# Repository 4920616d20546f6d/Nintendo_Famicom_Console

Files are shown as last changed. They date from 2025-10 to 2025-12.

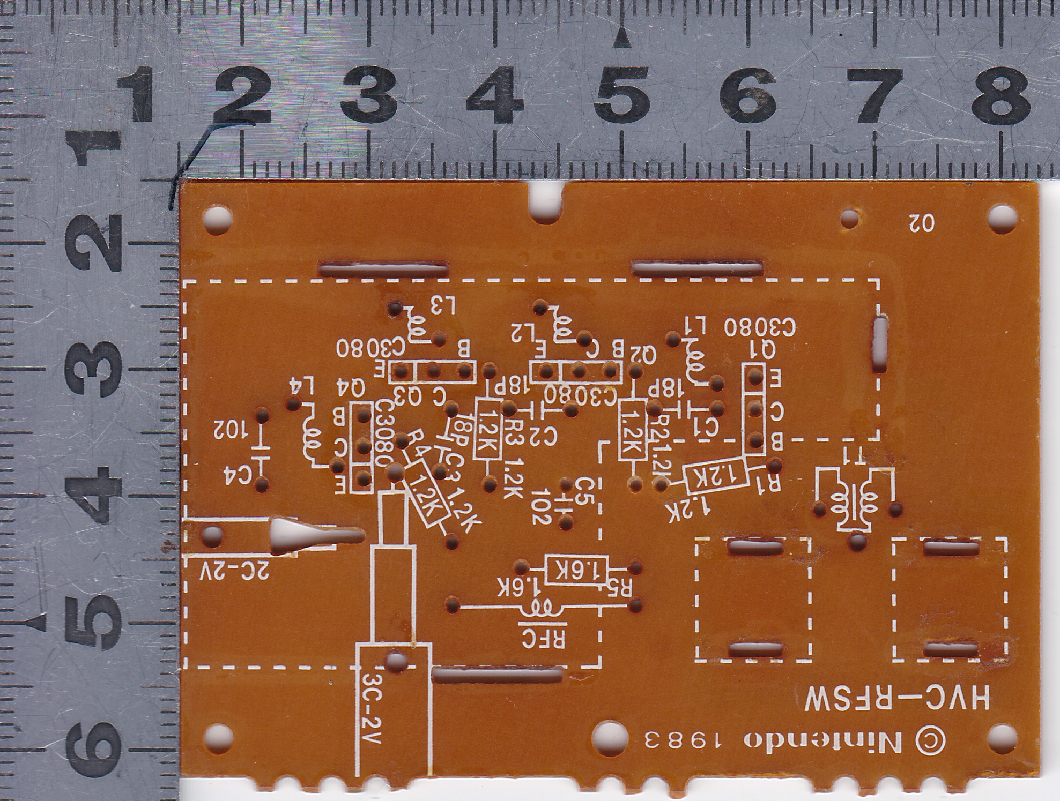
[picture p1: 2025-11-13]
RF_SWITCH/pcb_front_measure.jpg

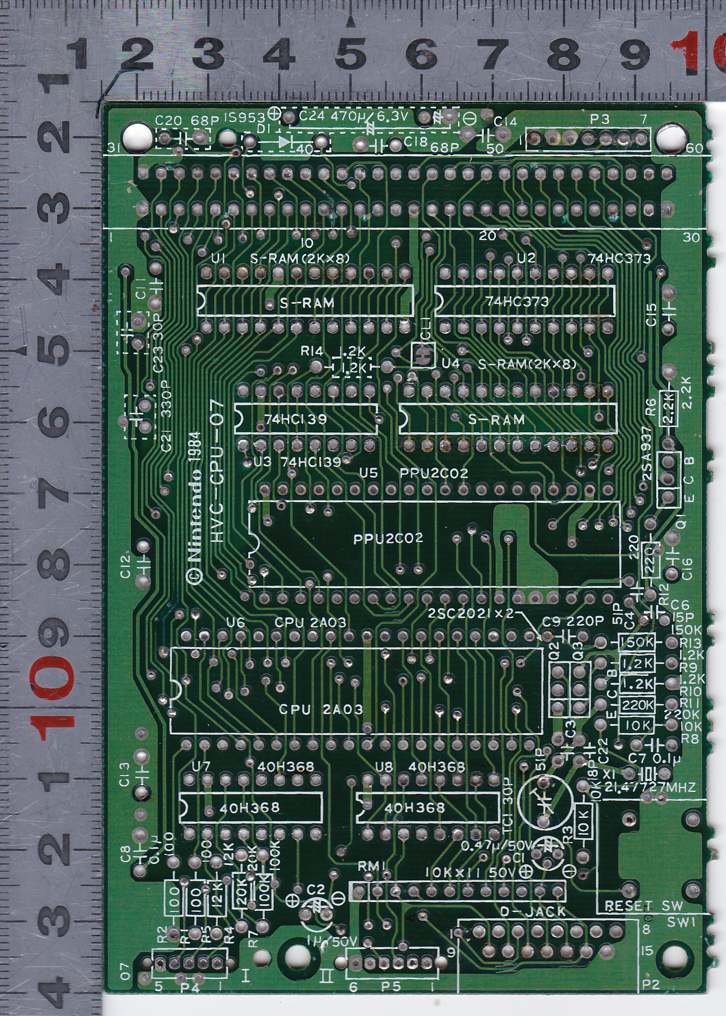
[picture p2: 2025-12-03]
HVC-CPU-07/pcb_front_measure.jpg

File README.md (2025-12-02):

# Goals
This project documents the Nintendo Family Computer from Japan. The goal is to provide complete, verified, schematics and PCB for every version of the console and essential accessories.

# Progress
- December 1, HVC-CPU-GPM-02 all footprints reviewed. Holes and pads corrected. Revision uploaded.
- November 30, HVC-CPU-GPM-02 verified to be electrically correct. There are 3 mechanical errors. The drill sizes for the 15 pin connector, TC1, and Reset switch are too small. Drills and annulus will be adjusted in next revision.
- November 27, HVC-CPU-07 acquired
- November 12, 2025 the HVC-CPU-GPM-02 mainboard was sent out for manufacturing.
- November 10, 2025 the first versions of all essential hardware and accessories have been complete and added to the repository.

# Project Status
## Console HVC-001
| Revision | Schematic | Symbols | Datasheets | Notes | PCB | Footprint | Pads | Masks | Text | Graphics | Models | Photos | Ready for Manufacturer | Manufactured |
|---|---|---|---|---|-----|---|---|---|---|---|---|---|---|---|
| HVC-CPU | ❌ | ❌ | ❌ | ❌ | ❌ | ❌ | ❌ | ❌ | ❌ | ❌ | ❌ | ❌ | ❌ | ❌ |
| HVC-CPU-02 | ❌ | ❌ | ❌ | ❌ | ❌ | ❌ | ❌ | ❌ | ❌ | ❌ | ❌ | ❌ | ❌ | ❌ |
| HVC-CPU-03 | ❌ | ❌ | ❌ | ❌ | ❌ | ❌ | ❌ | ❌ | ❌ | ❌ | ❌ | ❌ | ❌ | ❌ |
| HVC-CPU-04 | ❌ | ❌ | ❌ | ❌ | ❌ | ❌ | ❌ | ❌ | ❌ | ❌ | ❌ | ❌ | ❌ | ❌ |
| HVC-CPU-05 | ❌ | ❌ | ❌ | ❌ | ❌ | ❌ | ❌ | ❌ | ❌ | ❌ | ❌ | ❌ | ❌ | ❌ |
| HVC-CPU-06 | ❌ | ❌ | ❌ | ❌ | ❌ | ❌ | ❌ | ❌ | ❌ | ❌ | ❌ | ❌ | ❌ | ❌ |
| HVC-CPU-07 | ❌ | ❌ | ❌ | ❌ | ❌ | ❌ | ❌ | ❌ | ❌ | ❌ | ❌ | ❌ | ❌ | ❌ |
| HVC-CPU-GPM-01 | ❌ | ❌ | ❌ | ❌ | ❌ | ❌ | ❌ | ❌ | ❌ | ❌ | ❌ | ❌ | ❌ | ❌ |
| HVC-CPU-GPM-02 | ✔️ | ✔️ | ✔️ | ✔️ | ✔️ | ✔️ | ✔️ | ✔️ | ✔️ | ✔️ | ✔️ | ✔️ | ✔️ | ❗ |

## Controller 1
| Revision | Schematic | Symbols | Datasheets | Notes | PCB | Footprint | Pads | Masks | Text | Graphics | Models | Photos | Ready for Manufacturer | Manufactured |
|---|---|---|---|---|-----|---|---|---|---|---|---|---|---|---|
| Mitsumi 56 8231 B | ✔️ | ✔️ | ❗ | ✔️ | ✔️ | ✔️ | ✔️ | ✔️ | ✔️ | ✔️ | ❗ | ✔️ | ✔️ | ❗ |

## Controller 2
| Revision | Schematic | Symbols | Datasheets | Notes | PCB | Footprint | Pads | Masks | Text | Graphics | Models | Photos | Ready for Manufacturer | Manufactured |
|---|---|---|---|---|-----|---|---|---|---|---|---|---|---|---|
| Mitsumi 56 8232 A | ✔️ | ✔️ | ❗ | ✔️ | ✔️ | ✔️ | ✔️ | ✔️ | ✔️ | ✔️ | ❗ | ✔️ | ✔️ | ❗ |

## RF Modultaor
| Revision | Schematic | Symbols | Datasheets | Notes | PCB | Footprint | Pads | Masks | Text | Graphics | Models | Photos | Ready for Manufacturer | Manufactured |
|---|---|---|---|---|-----|---|---|---|---|---|---|---|---|---|
| 1988 for HVC-CPU-GPM-02 | ✔️ | ✔️ | ❗ | ✔️ | ✔️ | ✔️ | ✔️ | ✔️ | ✔️ | ✔️ | ❗ | ✔️ | ✔️ | ❗ |

## AC Power Adaptor HVC-002
| Revision | Schematic | Symbols | Datasheets | Notes | PCB | Footprint | Pads | Masks | Text | Graphics | Models | Photos | Ready for Manufacturer | Manufactured |
|---|---|---|---|---|-----|---|---|---|---|---|---|---|---|---|
| 1988 for HVC-CPU-GPM-02 | ✔️ | ✔️ | ❗ | ✔️ | ✔️ | ✔️ | ✔️ | ✔️ | ✔️ | ✔️ | ❗ | ✔️ | ✔️ | ❗ |

## RF Switch HVC-003
| Revision | Schematic | Symbols | Datasheets | Notes | PCB | Footprint | Pads | Masks | Text | Graphics | Models | Photos | Ready for Manufacturer | Manufactured |
|---|---|---|---|---|-----|---|---|---|---|---|---|---|---|---|
| HVC-RFSW | ✔️ | ✔️ | ❗ | ✔️ | ✔️ | ✔️ | ✔️ | ✔️ | ✔️ | ✔️ | ❗ | ✔️ | ✔️ | ❗ |

# Links
https://github.com/emu-russia/breaks

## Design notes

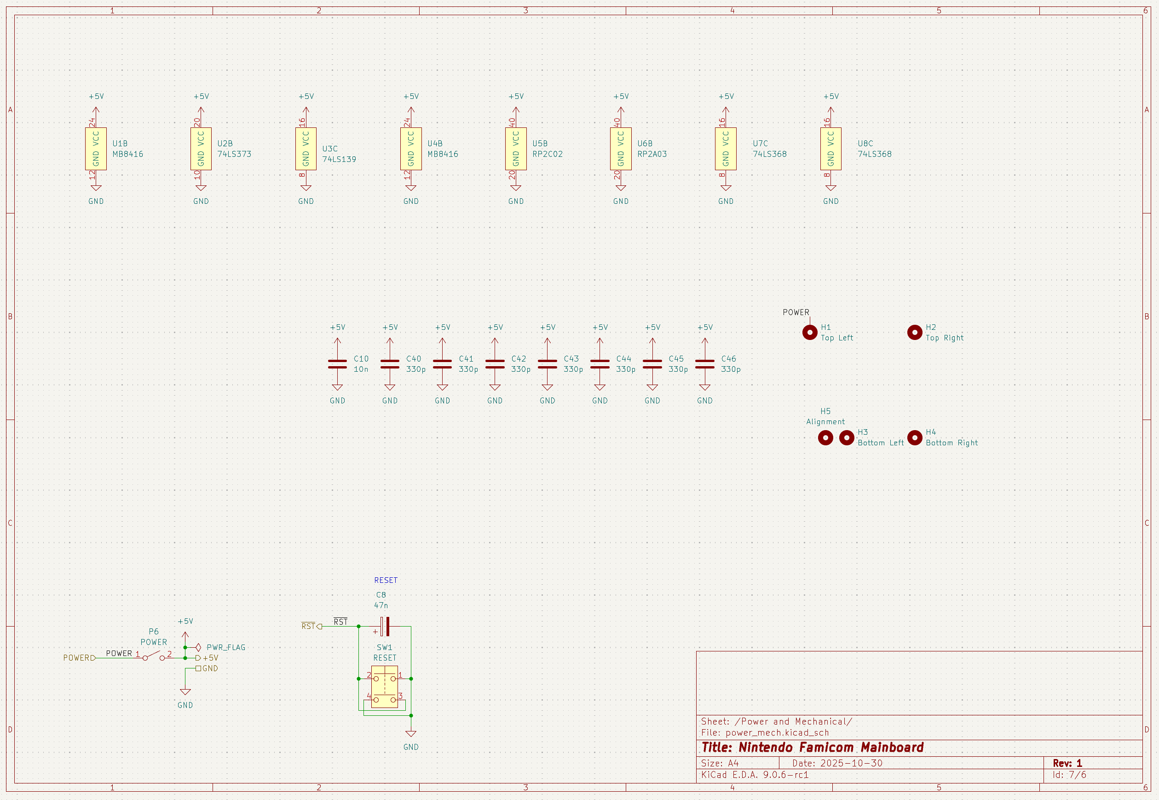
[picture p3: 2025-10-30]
HVC-CPU-GPM-02/HVC-CPU-GPM-02_schematic_power-mech.png

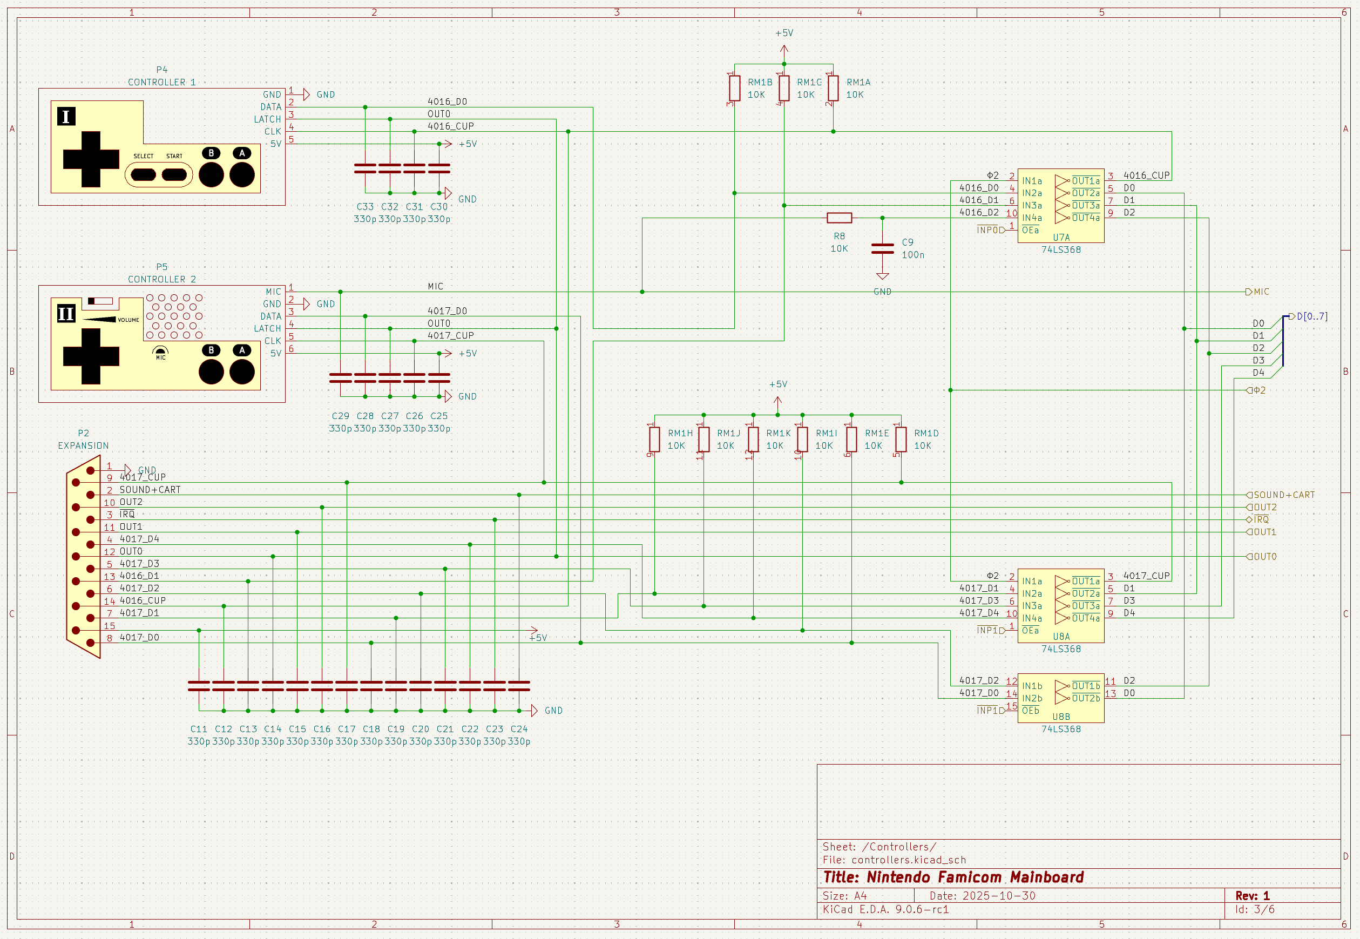
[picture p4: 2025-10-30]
HVC-CPU-GPM-02/HVC-CPU-GPM-02_schematic_controllers.png

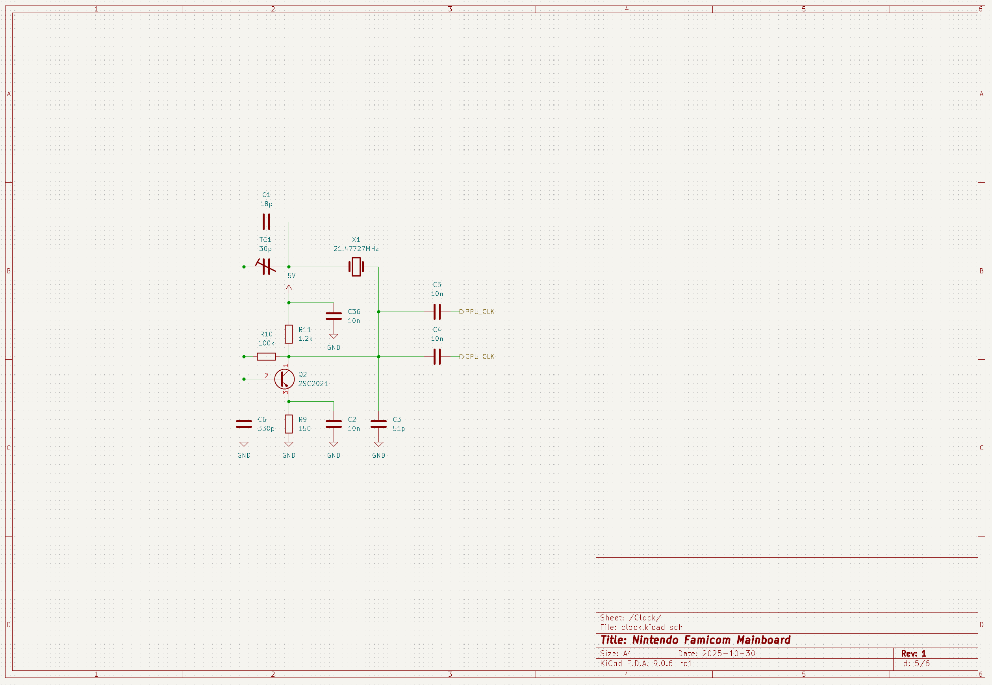
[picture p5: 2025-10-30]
HVC-CPU-GPM-02/HVC-CPU-GPM-02_schematic_clock.png

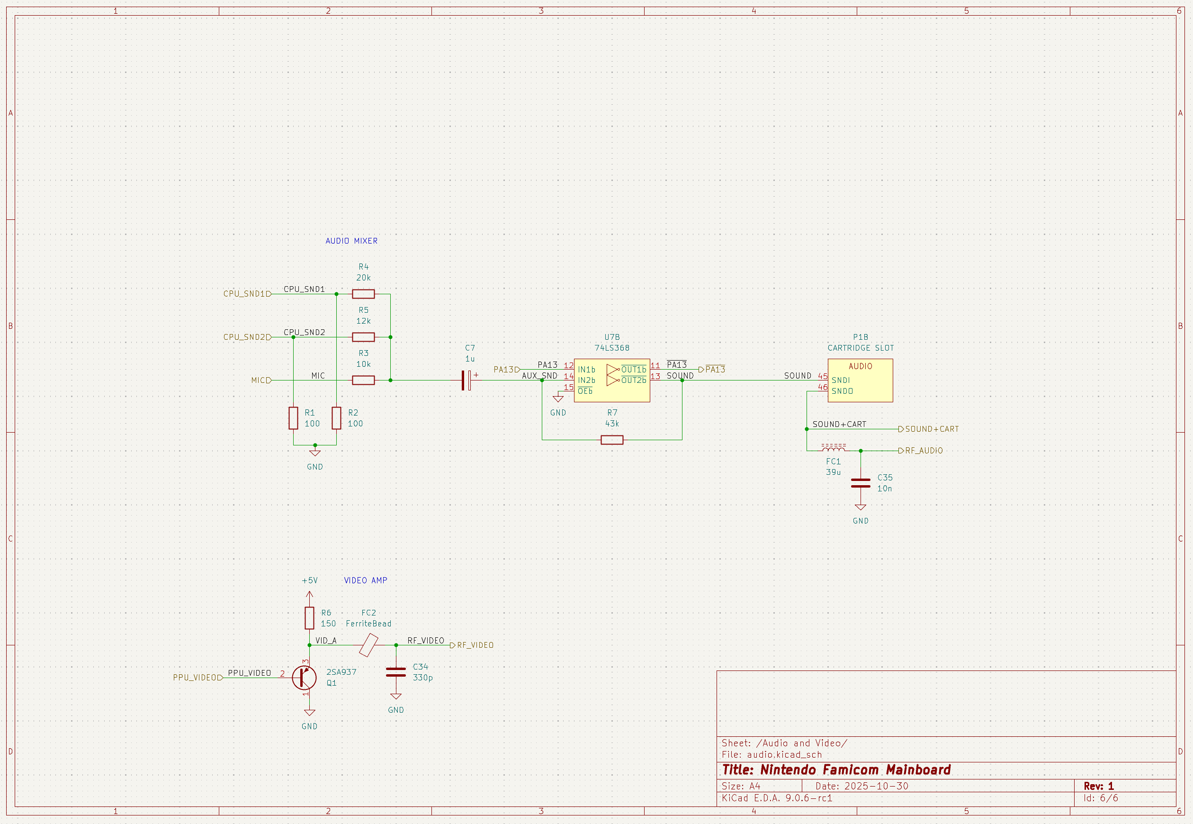
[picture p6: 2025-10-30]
HVC-CPU-GPM-02/HVC-CPU-GPM-02_schematic_audio-video.png

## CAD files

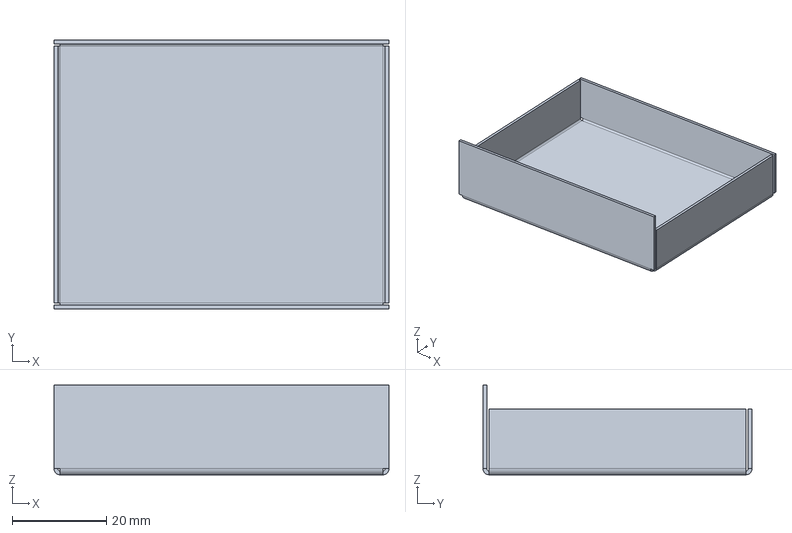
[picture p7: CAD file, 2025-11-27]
RF_MODULE/shield/body.FCStd
71.0 x 57.0 x 19.0 mm

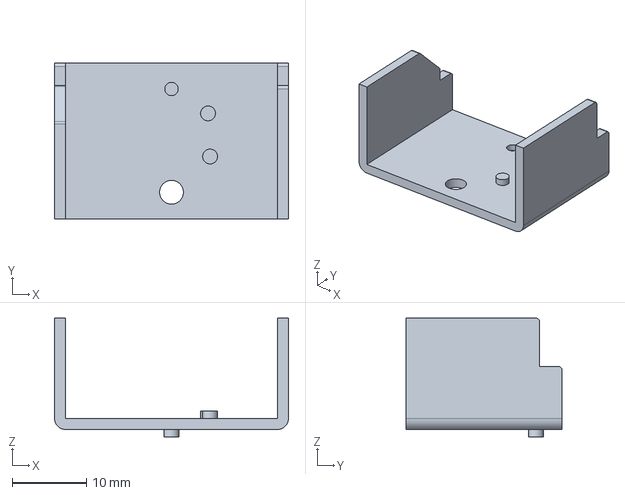
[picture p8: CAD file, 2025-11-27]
RF_MODULE/shield/heatsink.FCStd
31.5 x 21.0 x 16.0 mm

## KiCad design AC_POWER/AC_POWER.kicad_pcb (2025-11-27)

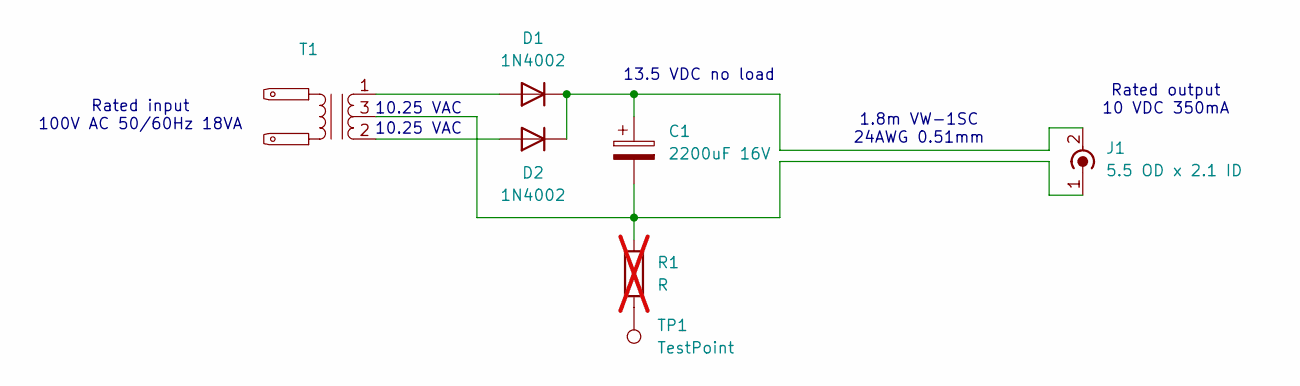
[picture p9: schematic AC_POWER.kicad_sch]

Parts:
C1: 2200uF 16V; capacitor
D1, D2: 1N4002; diode
J1: 5.5 OD x 2.1 ID; connector
R1: R; resistor; not fitted
T1: transformer
TP1: TestPoint; testpoint

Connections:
unnamed: D1.2 (A), T1.1
unnamed: C1.1, D1.1 (K), D2.1 (K), J1.2 (Ext)
unnamed: D2.2 (A), T1.2
unnamed: C1.2, J1.1 (In), R1.2, T1.3
unnamed: R1.1, TP1.1

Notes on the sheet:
Rated input 100V AC 50/60Hz 18VA
13.5 VDC no load
Rated output 10 VDC 350mA
1.8m VW-1SC 24AWG 0.51mm
10.25 VAC

Board: 2 copper layers, 7 parts (0 on the bottom side), 5 nets, no tracks yet.

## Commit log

2025-10-29 initial release
    [CONTROLLER2.kicad_sch, HVC-CPU-GPM-02.kicad_sch, audio.kicad_sch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]
2025-10-29 Refactor schematic: * Move audio and video circuits to dedicated sheet * Move power and mechanical to dedicated sheet Modify P1 Cart Connector symbol to: * split out audio ports * organize pins for e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
    [HVC-CPU-GPM-02.kicad_sch, audio.kicad_sch, clock.kicad_sch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]
2025-10-30 Change symbols to functional layout instead of pin map layout Add technical page to store pinouts Organize and compact root page
    [HVC-CPU-GPM-02.kicad_sch, audio.kicad_sch, clock.kicad_sch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]
2025-10-30 Rearranged pins on some symbols to simplify schematic wiring Removed schematics for controller PCBs Added PNG version of schematics
    [HVC-CPU-GPM-02.kicad_sch, audio.kicad_sch, clock.kicad_sch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]
2025-10-31 Update most custom footprints to remove Silkscreen layer - Since the PCB was originally hand drawn, the silkscreen for the footprint, and other graphics is not consistent. - The silkscreen is removed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
2025-11-11 add Controller 1 and RF module schematics and PCBs
    [CONTROLLER1.kicad_sch, RF_MODULE.kicad_sch]
2025-11-11 clean up RF modulator schematic and PCB
    [RF_MODULE.kicad_sch]
2025-11-12 add AC POWER adapter
    [AC_POWER.kicad_pcb, AC_POWER.kicad_sch]
2025-11-12 add solder mask to PCB and clarify notes on schematic
    [AC_POWER.kicad_pcb, AC_POWER.kicad_sch]
2025-11-13 adding RF_SWITCH PCBs and schematics
    [RF_SWITCH.kicad_sch]
2025-11-27 annotate schematics, correct PCB/schematic parity issure, add datasheets
    [AC_POWER.kicad_pcb, audio.kicad_sch, body.FCStd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]
2025-11-27 add links to PPU and APU reverse engineering books
    [power_mech.kicad_sch]
2025-12-01 Updated PCB and footprints to correct hole and pad sizes
    [clock.kicad_sch, controllers.kicad_sch, power_mech.kicad_sch]
2025-12-03 add PCB images for HVC-CPU-07
2025-12-06 Adding HVC-CPU-07 revision schematics and PCB layout
    [audio.kicad_sch, clock.kicad_sch, controllers.kicad_sch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]
